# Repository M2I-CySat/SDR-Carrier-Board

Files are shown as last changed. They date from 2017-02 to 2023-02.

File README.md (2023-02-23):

# Cysat-1 Software Defined Radio Adapter Board

The Breakout board contains the LNA and band pass filters as well as the SDR used on the satellite. This is a four layer board that has the LNA and RF paths on one side and the FPGA on the other side. A .1" pin header is used to break out the RX/TX lines and an Enable pin to be connected to the PC104 bus and to the rest of the on board electronics.

RF Cables are used to connect the signal from the antenna to the LNAs and a small RF cables is then used to connect the output from the LNA to the FPGA board. RF is present on the board (hence the four layer design) but RF on the FPGA board is only accessible via MCX connectors on the FPGA board itself.
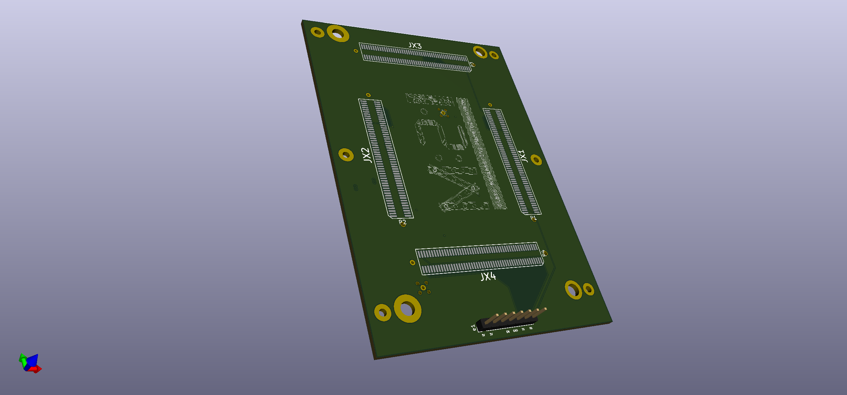
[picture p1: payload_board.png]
breakout board


### footprints

This folder contains the footprint libraries for some of the SDR carrier board components
that are used to translate the schematic to a PCB board design in KiCad.

### schematics
This folder contains the SDR carrier "breakout board" KiCad project. In this folder you will
find all of the necessary library and other footprint libraries. This also contains all of 
the necessary files for the KiCad project.

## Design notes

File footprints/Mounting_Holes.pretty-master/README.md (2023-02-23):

# Mounting_Holes.pretty

This repository is now considered legacy and will not accept any further pull requests.

To contribute, refer to the new footprints library at https://github.com/kicad/kicad-footprints

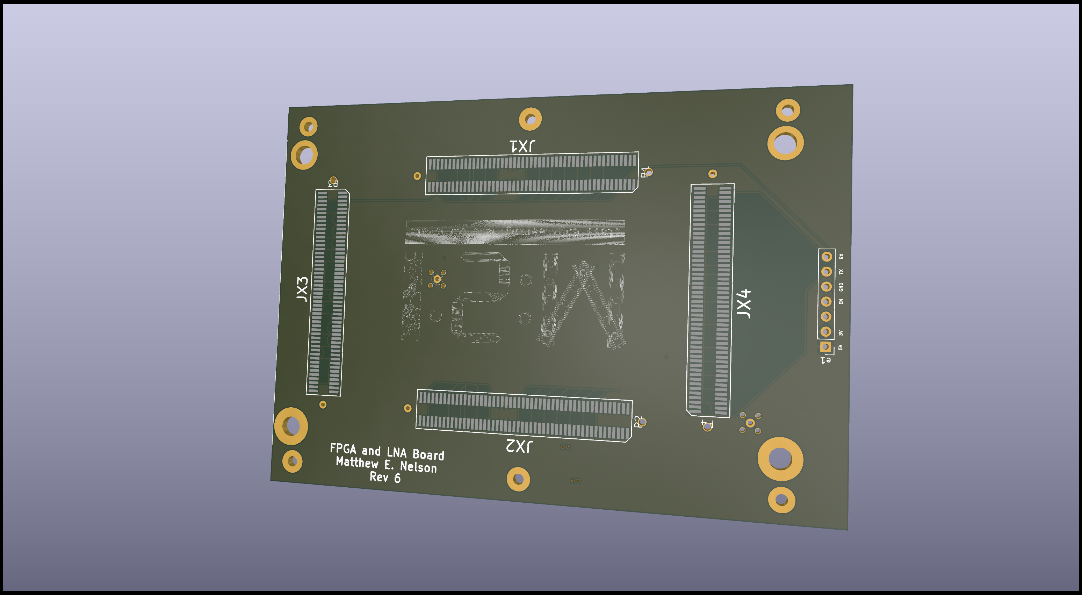
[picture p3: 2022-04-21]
schematics/breakoutBoard/payload_board.png

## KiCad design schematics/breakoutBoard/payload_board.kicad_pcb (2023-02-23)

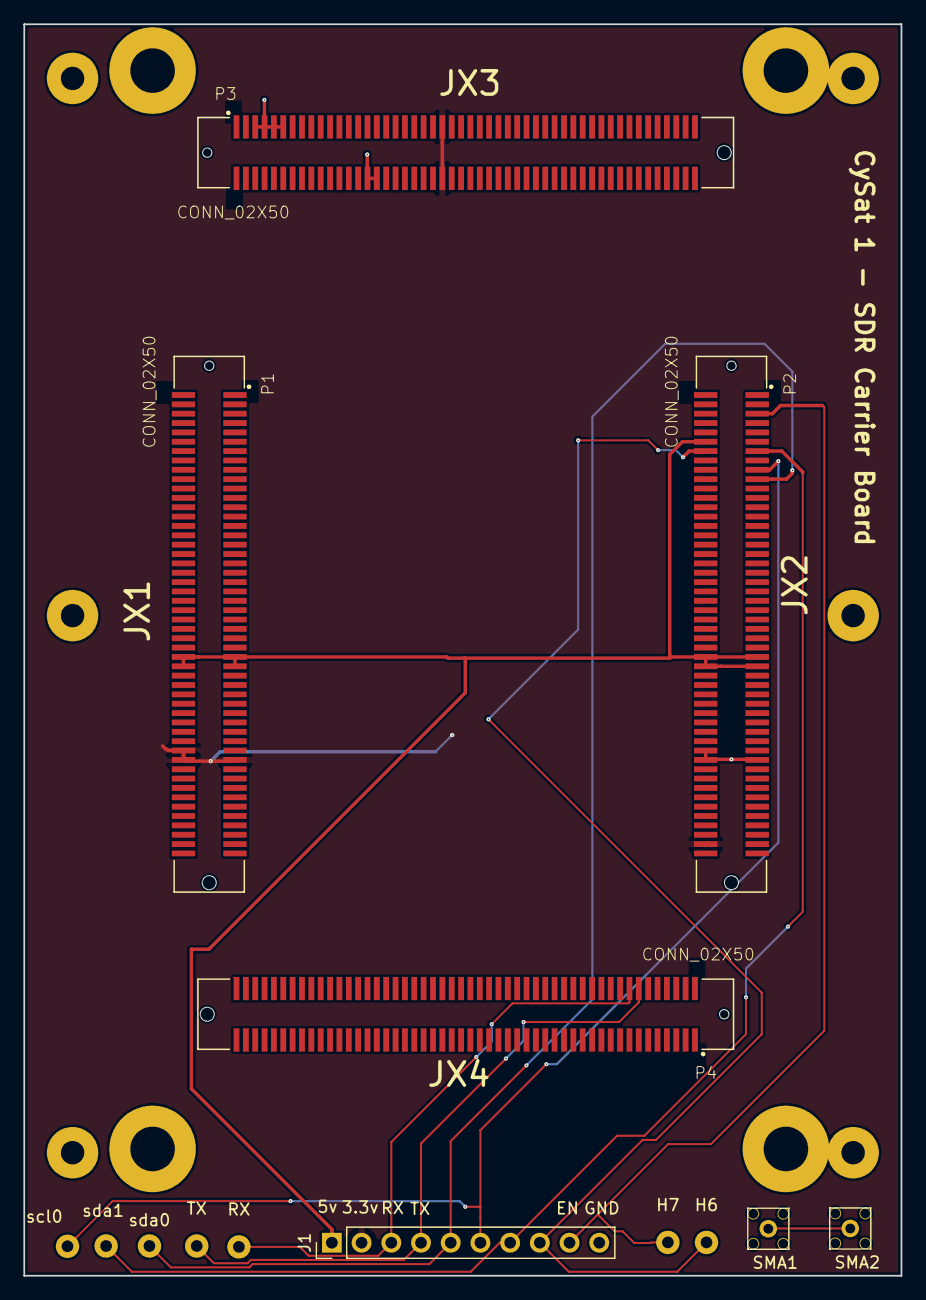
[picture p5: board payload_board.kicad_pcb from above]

Board: 2 copper layers, 75.0 x 107.0 mm, 14 parts (0 on the bottom side), 11 nets.

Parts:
H6, H7: MountingHole_Pad; MountingHole_2.2mm_M2_Pad
J1: Conn_01x10; PinHeader_1x10_P2.54mm_Vertical
P1, P2, P3, P4: CONN_02X50; FCI_61083-101400LF
RX: MountingHole_Pad; MountingHole_2.2mm_M2_Pad
SMA1, SMA2: Molex-MMCX-SMD; Molex MMCX SMD 50Ohm
TX: MountingHole_Pad; MountingHole_2.2mm_M2_Pad
scl0: MountingHole_Pad; MountingHole_2.2mm_M2_Pad
sda0, sda1: MountingHole_Pad; MountingHole_2.2mm_M2_Pad

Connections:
/3.3v: J1.2, P1.78, P1.79, P1.80, P2.98, P3.45, P3.46
/5v: J1.1, P1.57, P1.58, P1.59, P1.60, P2.12, P2.57, P2.58, P2.59, P2.60
/ENABLE: H7.1, J1.9, P2.5
/GND: J1.10, P2.78, P2.79, P2.80, P3.5, P3.7, P3.9, P3.11, P3.30, P3.32
/SCL0: J1.6, P2.17, scl0.1
/SCL1: H6.1, J1.8, P2.14
/SDA0: J1.5, P2.19, sda0.1
/SDA1: J1.7, P2.13, sda1.1
/UART_RX: J1.3, P4.16, RX.1
/UART_TX: J1.4, P4.14, TX.1
unnamed: SMA1.1, SMA2.1

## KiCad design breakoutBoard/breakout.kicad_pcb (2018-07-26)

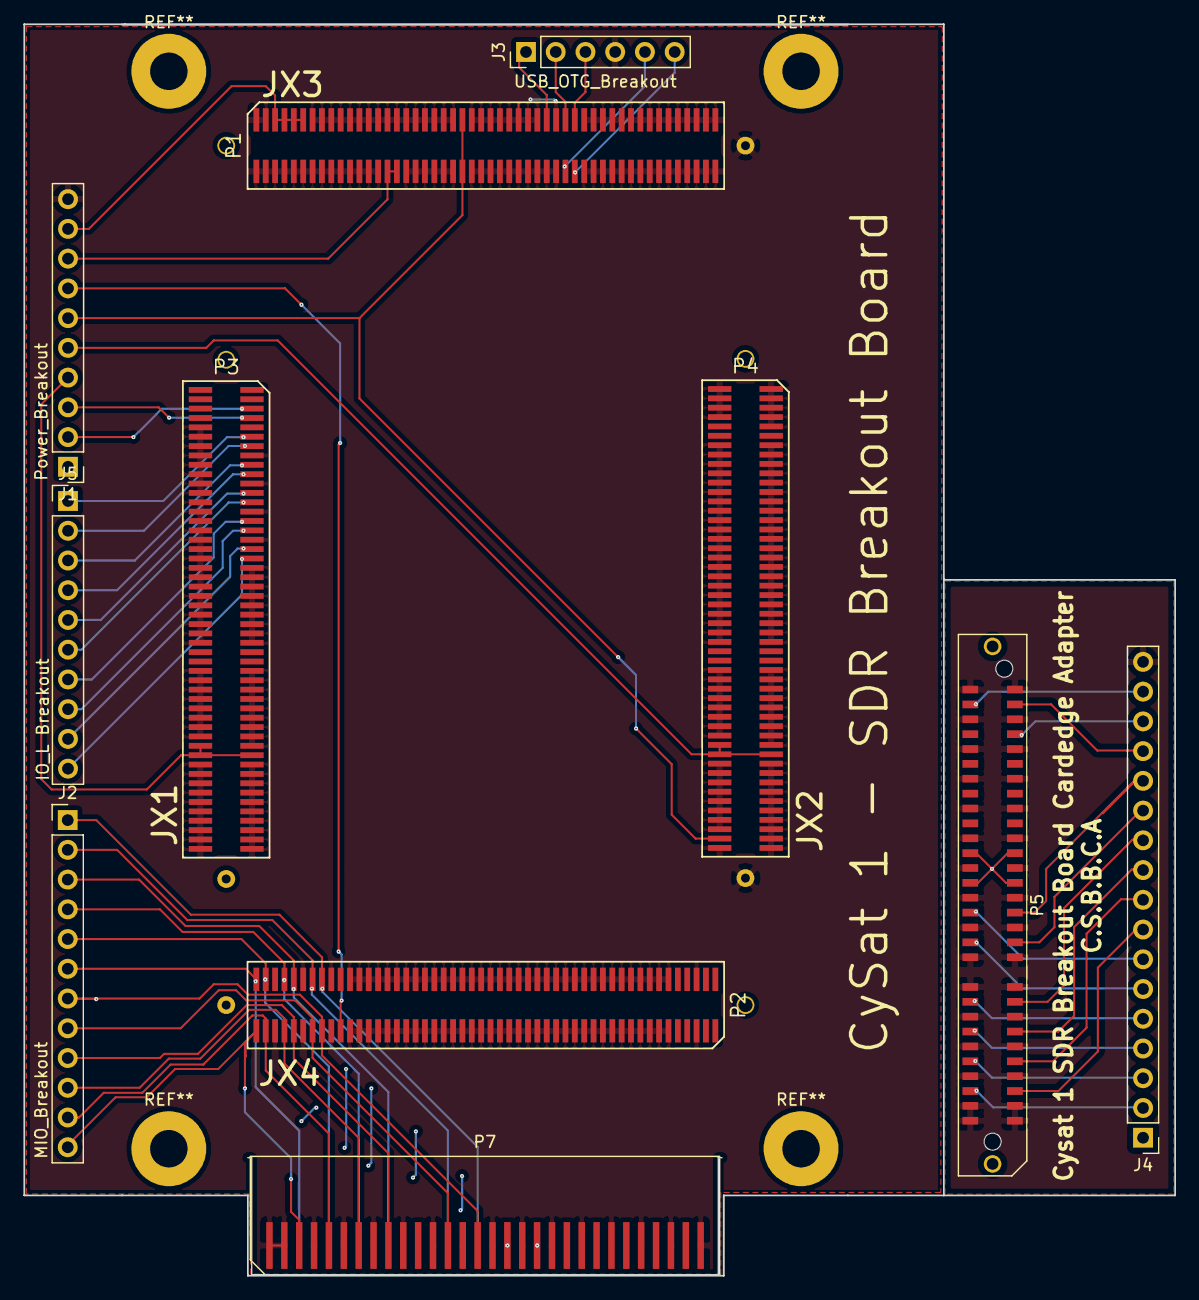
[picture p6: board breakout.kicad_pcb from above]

Board: 2 copper layers, 78.5 x 106.9 mm, 11 parts (0 on the bottom side), 39 nets.

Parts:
J1: Power_Breakout; Pin_Header_Straight_1x10_Pitch2.54mm
J2: MIO_Breakout; Pin_Header_Straight_1x12_Pitch2.54mm
J3: USB_OTG_Breakout; Pin_Header_Straight_1x06_Pitch2.54mm
J4: Cardedge breakout; Pin_Header_Straight_1x17_Pitch2.54mm
J5: IO_L Breakout; Pin_Header_Straight_1x10_Pitch2.54mm
P1, P2, P3, P4: CONN_02X50; BERGSTAK_100_PIN1_RIGHT
P5: CONN_02X30; MECF-30-01-L-DV-WT_Socket
P7: CONN_02X30; MECF-30-0_-NP-L-DV_Edge

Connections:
3V3_I2C: J1.7, P2.81
+5V: J1.1, J4.1, P3.57, P3.58, P3.59, P3.60, P4.12, P4.57, P4.58, P4.59, P4.60, P5.33, P5.34, P5.37, P5.38, P7.33, P7.34, P7.37, P7.38
FPGA_DONE: J4.16, P3.8, P5.58, P7.58
FPGA_VBATT: J1.3, P3.7
GND: J1.10, J3.4, J4.17, P1.1, P1.2, P1.3, P1.4, P1.6, P1.8, P1.10, P1.12, P1.13, P1.14, P1.15, P1.16, P1.17, P1.18, P1.19, P1.20, P1.21, P1.22, P1.23, P1.24, P1.25, P1.26, P1.27, P1.28, P1.29, P1.31, P1.33, P1.34, P1.35, P1.36, P1.37, P1.38, P1.39, P1.40, P1.41, P1.42, P1.43, P1.44, P1.47, P1.48, P1.49, P1.50, P1.51, P1.52, P1.53, P1.54, P1.55, P1.56, P1.57, P1.58, P1.59, P1.60, P1.61, P1.62, P1.64, P1.65, P1.66, P1.71, P1.72, P1.73, P1.74, P1.75, P1.76, P1.77, P1.78, P1.79, P1.80, P1.81, P1.82, P1.83, P1.84, P1.85, P1.86, P1.87, P1.88, P1.89, P1.90, P1.91, P1.92, P1.93, P1.94, P1.95, P1.96, P1.97, P1.98, P1.99, P1.100, P2.5, P2.6, P2.11, P2.12, P2.13, P2.14, P2.15, P2.16, P2.17, P2.18, P2.19, P2.20, P2.21, P2.22, P2.23, P2.24, P2.25, P2.26, P2.27, P2.28, P2.29, P2.30, P2.31, P2.32, P2.33, P2.34, P2.35, P2.36, P2.37, P2.38, P2.39, P2.40, P2.41, P2.42, P2.43, P2.44, P2.45, P2.46, P2.47, P2.48, P2.49, P2.50, P2.51, P2.52, P2.53, P2.54, P2.55, P2.56, P2.57, P2.58, P2.59, P2.60, P2.61, P2.62, P2.63, P2.64, P2.65, P2.66, P2.67, P2.68, P2.69, P2.70, P2.71, P2.72, P2.73, P2.74, P2.75, P2.76, P2.77, P2.78, P2.79, P2.80, P2.83, P2.84, P2.89, P2.90, P2.95, P2.96, P3.10, P3.12, P3.14, P3.15, P3.16, P3.18, P3.20, P3.21, P3.22, P3.24, P3.26, P3.27, P3.28, P3.30, P3.32, P3.33, P3.34, P3.36, P3.38, P3.39, P3.40, P3.41, P3.42, P3.43, P3.44, P3.45, P3.46, P3.47, P3.48, P3.49, P3.50, P3.51, P3.52, P3.53, P3.54, P3.55, P3.56, P3.61, P3.62, P3.63, P3.64, P3.65, P3.66, P3.67, P3.68, P3.69, P3.70, P3.71, P3.72, P3.73, P3.74, P3.75, P3.76, P3.77, P3.81, P3.82, P3.83, P3.84, P3.85, P3.86, P3.87, P3.88, P3.89, P3.90, P3.91, P3.92, P3.93, P3.94, P3.95, P3.96, P3.97, P3.98, P3.99, P3.100, P4.1, P4.2, P4.3, P4.4, P4.5, P4.6, P4.7, P4.8, P4.9, P4.13, P4.14, P4.15, P4.16, P4.17, P4.18, P4.19, P4.20, P4.21, P4.22, P4.23, P4.24, P4.25, P4.26, P4.27, P4.28, P4.29, P4.30, P4.31, P4.32, P4.33, P4.34, P4.35, P4.36, P4.37, P4.38, P4.39, P4.40, P4.41, P4.42, P4.43, P4.44, P4.45, P4.46, P4.47, P4.48, P4.49, P4.50, P4.51, P4.52, P4.53, P4.54, P4.55, P4.56, P4.61, P4.62, P4.63, P4.64, P4.65, P4.66, P4.67, P4.68, P4.69, P4.70, P4.71, P4.72, P4.73, P4.74, P4.75, P4.76, P4.77, P4.81, P4.82, P4.83, P4.84, P4.85, P4.86, P4.87, P4.88, P4.89, P4.90, P4.91, P4.92, P4.93, P4.94, P4.95, P4.96, P4.97, P4.99, P4.100, P5.1, P5.2, P5.3, P5.4, P5.7, P5.8, P5.11, P5.12, P5.15, P5.16, P5.19, P5.20, P5.23, P5.24, P5.27, P5.28, P5.31, P5.32, P5.35, P5.36, P5.39, P5.40, P5.43, P5.44, P5.47, P5.48, P5.51, P5.52, P5.55, P5.56, P5.59, P5.60, P7.1, P7.2, P7.3, P7.4, P7.7, P7.8, P7.11, P7.12, P7.15, P7.16, P7.19, P7.20, P7.23, P7.24, P7.27, P7.28, P7.31, P7.32, P7.35, P7.36, P7.39, P7.40, P7.43, P7.44, P7.47, P7.48, P7.51, P7.52, P7.55, P7.56, P7.59, P7.60
IO_L01_33_JX1_N: J5.10, P3.37
IO_L01_33_JX1_P: J5.9, P3.35
IO_L16_33_JX1_N: J5.2, P3.13
IO_L16_33_JX1_P: J5.1, P3.11
IO_L18_33_JX1_N: J5.4, P3.19
IO_L18_33_JX1_P: J5.3, P3.17
IO_L20_33_JX1_N: J5.6, P3.25
IO_L20_33_JX1_P: J5.5, P3.23
IO_L22_33_JX1_N: J5.8, P3.31
IO_L22_33_JX1_P: J5.7, P3.29
JX_MGTAVCC: J1.9, P1.5, P1.7, P1.9, P1.11
JX_MGTAVTT: J1.8, P1.30, P1.32
JX_VCCO_12: J1.4, P3.78, P3.79, P3.80
JX_VCCO_13: J1.6, P1.45, P1.46, P4.98
JX_VCCO_33_34: J1.5, P4.78, P4.79, P4.80
MIO0: J2.11, J4.9, P2.97, P5.9, P7.9
MIO10: J2.8, J4.12, P2.87, P5.25, P7.25
MIO11: J2.2, J4.6, P2.88, P5.26, P7.26
MIO12: J2.1, J4.7, P2.86, P5.30, P7.30
MIO13: J2.9, J4.11, P2.91, P5.17, P7.17
MIO14: J2.10, J4.10, P2.93, P5.13, P7.13
MIO15: J2.7, J4.13, P2.85, P5.29, P7.29
MIO46: J2.3, J4.5, P2.92, P5.18, P7.18
MIO47: J2.4, J4.4, P2.94, P5.14, P7.14
MIO48: J2.12, J4.8, P2.99, P5.5, P7.5
MIO49: J2.5, J4.3, P2.98, P5.10, P7.10
MIO51: J2.6, J4.2, P2.100, P5.6, P7.6
PG_MODULE: J4.15, P4.11, P5.53, P7.53
PWR_ENABLE: J1.2, J4.14, P3.5, P5.57, P7.57
USB_ID: J3.1, P1.63
USB_OTG_CPEN: J3.6, P1.70
USB_OTG_N: J3.3, P1.69
USB_OTG_P: J3.2, P1.67
USB_VBUS_OTG: J3.5, P1.68

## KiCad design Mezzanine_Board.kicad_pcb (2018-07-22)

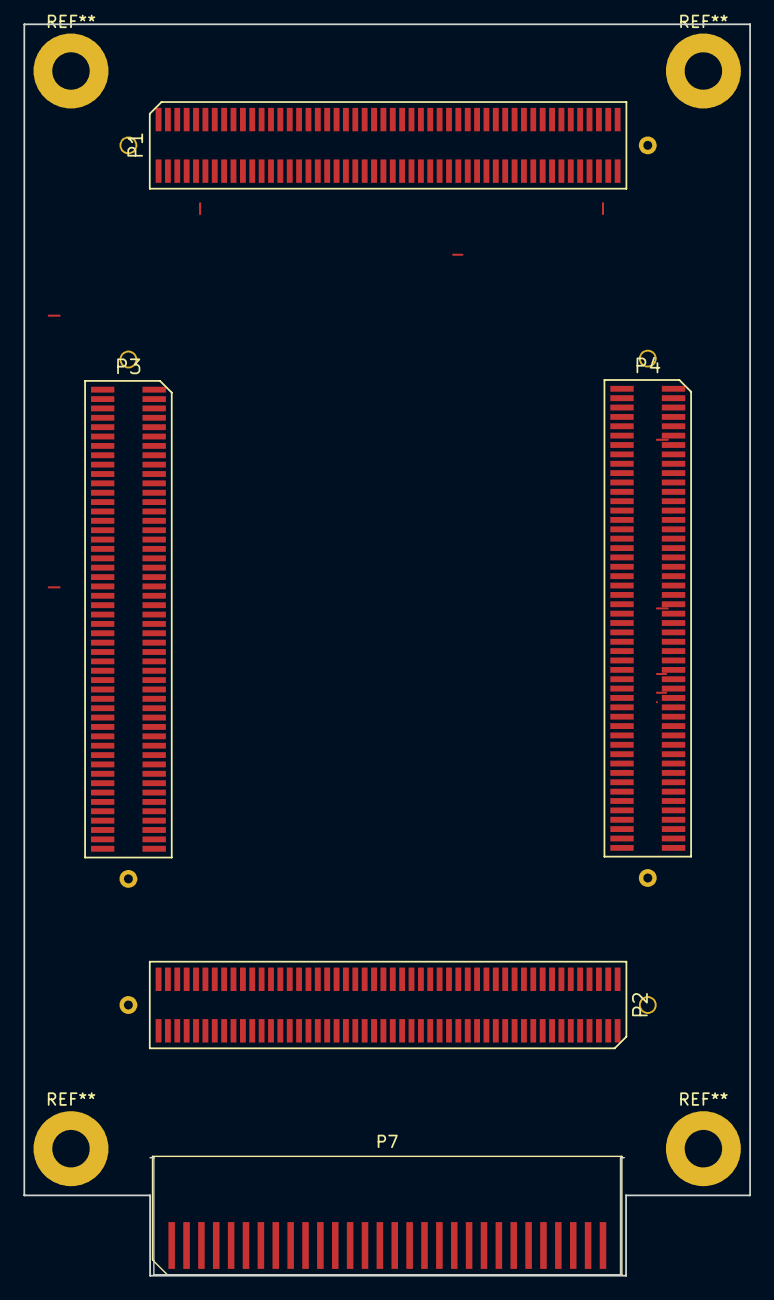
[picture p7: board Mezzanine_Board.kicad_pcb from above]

Board: 2 copper layers, 62.0 x 106.9 mm, 5 parts (0 on the bottom side), 20 nets.

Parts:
P1, P2, P3, P4: CONN_02X50; BERGSTAK_100_PIN1_RIGHT
P7: CONN_02X30; MECF-30-0_-NP-L-DV_Edge

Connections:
+3V3: P7.2, P7.11, P7.14, P7.33, P7.36, P7.53, P7.56
+5V: P7.3, P7.57
+12V: P7.6, P7.60
/1V0_AVCC: P3.6, P3.8, P3.10, P3.12
/1V2_AVTT: P3.29, P3.31
/1V8: P2.77, P2.79, P2.80
/ETH1_RX_CLK: P4.41, P4.45
/FMC_LA07_P: P3.63, P3.65
/FMC_LA08_N: P3.70, P3.76
/FMC_LA08_P: P3.68, P3.74
/I2C2_SCL: P2.69, P2.70
/I2C2_SDA: P2.67, P2.68
/SPI2_MISO: P4.75, P7.15
/SPI2_MOSI: P4.80, P7.18
/SPI2_SCK: P4.78, P7.19
/SYS_SCL: P4.93, P7.7
/SYS_SDA: P4.91, P7.10
/VADJ: P1.77, P1.79, P1.80, P2.97, P3.45, P3.46
/VIN_HDR: P1.57, P1.58, P1.59, P1.60, P2.11, P2.57, P2.58, P2.59, P2.60
GND: P1.15, P1.16, P1.21, P1.22, P1.27, P1.28, P1.33, P1.34, P1.39, P1.40, P1.45, P1.46, P1.51, P1.52, P1.65, P1.66, P1.71, P1.72, P1.78, P1.85, P1.86, P1.95, P1.96, P2.15, P2.16, P2.21, P2.22, P2.27, P2.28, P2.33, P2.34, P2.39, P2.40, P2.45, P2.46, P2.51, P2.52, P2.65, P2.66, P2.71, P2.72, P2.78, P2.85, P2.86, P2.91, P2.92, P3.5, P3.11, P3.17, P3.18, P3.23, P3.24, P3.30, P3.36, P3.39, P3.49, P3.50, P3.55, P3.56, P3.61, P3.62, P3.66, P3.71, P3.72, P3.77, P3.78, P3.83, P3.84, P3.89, P3.90, P3.95, P3.96, P4.5, P4.6, P4.11, P4.12, P4.17, P4.18, P4.23, P4.24, P4.29, P4.30, P4.39, P4.40, P4.49, P4.50, P4.55, P4.56, P4.61, P4.62, P4.65, P4.66, P4.71, P4.72, P4.83, P4.84, P4.89, P4.90, P4.95, P4.96, P7.1, P7.4, P7.5, P7.8, P7.9, P7.12, P7.13, P7.16, P7.17, P7.20, P7.23, P7.26, P7.27, P7.30, P7.31, P7.34, P7.35, P7.38, P7.39, P7.42, P7.43, P7.46, P7.47, P7.50, P7.51, P7.54, P7.55, P7.58, P7.59

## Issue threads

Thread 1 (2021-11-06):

Power feed to SDR SOM

matgyver, 2021-11-06:
SOM requires 5V not 3.3V. 3.3 is not needed on this board anymore, remove 3.3 and make sure 5V is running to JX1[57:60], JX2[12,57:60]

Closed 2022-04-21.

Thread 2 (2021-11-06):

Swap RX and TX pins

matgyver, 2021-11-06:
RX and TX pins on the board are mis-labeled

Closed 2022-04-21.

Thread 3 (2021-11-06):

Add additional ground connections

matgyver, 2021-11-06:
It is recommended that all pins labeled ground be grounded. Ensure all pins are set to ground

JX4[5,6,11,12,17,18,23,24,29,30,39,40,49,50,55,56,61,62,65,66,71,72,83,84,89,90,95,96]

JX3[6,12,17,28,23,24,29,30,35,36,40,49,50,55,56,61,62,71,72,77,78,83,84,89,90,95,96]

JX2[15,16,21,22,27,28,33,34,39,40,45,46,51,52,65,66,71,72,77,85,86,91,92]

JX1[15,16,21,22,27,28,33,34,39,40,45,46,51,52,65,66,71,72,77,85,86,95,96]

matgyver, 2022-04-21:
Resolved in #691e69

Closed 2022-04-21.

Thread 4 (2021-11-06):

Add power filtering

matgyver, 2021-11-06:
Add some power filtering to keep the power to the LNA's as close to 5V as possible.

matgyver, 2022-04-20:
Not needed, closing

Closed 2022-04-20.

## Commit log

2018-07-24 Created new board, breakout
    [_saved_payload_board.sch, breakout.kicad_pcb, payload_board.sch]
2018-07-25 Started work on breakout board
    [_saved_payload_board.sch]
2018-07-25 Corrected and added basic pinout
    [_saved_payload_board.sch]
2018-07-25 Basic pinout done and start of routing
    [breakout.kicad_pcb, payload_board.sch]
2018-07-25 Added zones
    [_saved_payload_board.sch, breakout.kicad_pcb]
2018-07-25 Started routing
    [_saved_payload_board.sch, breakout.kicad_pcb, payload_board.sch]
2018-07-26 Work on schematic and traces
    [_saved_payload_board.sch, breakout.kicad_pcb, payload_board.sch]
2018-07-26 Completed routing and added gerber
    [_saved_payload_board.sch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]
2018-07-27 Adding some of those personal touches
    [_saved_payload_board.sch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]
2018-07-27 cleaning up
    [Mezzanine_Board.kicad_pcb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]
2018-07-27 Added notch to avoid pc104 header
    [breakout-B.Cu.gbr, breakout-B.Mask.gbr, breakout-B.SilkS.gbr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]
2018-07-29 update gerber
    [_saved_payload_board.sch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]
2018-07-30 Fixed gerber files
    [_saved_payload_board.sch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]
2018-07-31 Split into two boards and much futzing later the boards have been accepted
    [CardedgeBreakout-B.Cu.gbr, CardedgeBreakout-B.Mask.gbr, CardedgeBreakout-B.SilkS.gbr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]
2018-09-15 Updating files
    [payload_board-2018-07-27-13-58-27.sch]
2019-04-30 completed layout w/o impedance matching
    [CardedgeBreakout.kicad_pcb, Mezzanine_Board.kicad_pcb, breakout.kicad_pcb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]
2019-05-03 'final' push
    [payload_board.kicad_pcb, payload_board.sch]
2019-05-03 final board v2, now with UART
    [breakout-B.Cu.gbr, breakout-B.Mask.gbr, breakout-B.SilkS.gbr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]
2021-07-19 Files updated based on recent version sent to fab house
    This more recent revision fixes the FPGA connector issue and adds the LNA board to the backside. Board was changed from a 2-layer to a 4-layer board due to the additional RF components added.
    [LNA.sch, payload_board.kicad_pcb]
2021-08-11 Updated to FPGA connector
    Rotated connectors to match what is on the board.
    [payload_board.kicad_pcb]
2021-08-20 Final updates that were sent for fabrication
    [payload_board-B_Cu.gbr, payload_board-B_Mask.gbr, payload_board-B_SilkS.gbr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]
2021-11-05 Board fix
    Board fix that was not uploaded to GitHub plus one slight modification to reduce the cutout from the TX/RX lines
    [payload_board-B_Cu.gbr, payload_board-B_Mask.gbr, payload_board-B_SilkS.gbr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]
2021-11-06 Minor updates
    [payload_board.kicad_pcb]
2021-11-06 some fixes
    [payload_board.sch]
2021-11-06 Made fixes to schematic
    Swapped RX/TX pins, removed 3.3 and moved power to 5V rail. Added additional 5V pin, added RF GND pin to breakout. Addresses issues #1 and #2
    [payload_board.sch]
2021-11-07 Updated schematic
    Cleaned up wires and re-did labels. Added additional grounds and verified pwr, TX and RX. Reference to Issues #1, #2, #3 and #5.
    [LNA.sch, payload_board.sch]
2021-11-16 Added power filter
    [LNA.sch]
2022-04-20 Updated board to KiCad 6, pushing previous changes made.
    [LNA.kicad_sch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]
2022-04-21 Fixed grounding issue
    [LNA.kicad_sch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]
2023-02-23 Move files from main repo
    [CardedgeBreakout-B.Cu.gbr, CardedgeBreakout-B.Mask.gbr, CardedgeBreakout-B.SilkS.gbr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]
